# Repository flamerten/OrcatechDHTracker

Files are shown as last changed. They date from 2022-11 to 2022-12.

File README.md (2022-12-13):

# Orcatech DH Tracker

This is the GitHub repository for the Dining Hall Capacity Tracking project.

The process has been documented in this report: [Orcatech DH Project Report](./Orcatech_DHProject_Report.md)

The remaining contents of the repository are arranged as follows:

| Directory | Contents |
| --- | --- |
| [Electrical](./Electrical/) | Schematic and PCB design for the sensor nodes (designed using EasyEDA) |
| [Mechanical](./Mechanical/) | Files for the 3D printed PCB enclosure (in STL and SLDPRT format) |
| [Firmware](./Firmware/) | ESP32 Arduino source code for the sensor nodes |
|[Software](./Software/) | Python scripts to host the Telegram Bot and handle MQTT communication between the ESP32s, along with instructions to set up the Raspberry Pi network services |

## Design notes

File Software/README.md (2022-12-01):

# Raspberry Pi Setup

## Network Architecture

As the ESP32s are unable to connect to WPA2-Enterprise networks, the Raspberry Pi hosts a WPA2-Personal network using the built-in WiFi interface card `wlan_internal` to creates an intranet hotspot. Using the hotspot, one can SSH into the Raspberry Pi. The Raspberry Pi also hosts an MQTT broker for the ESP32s communicate sensor information in real time. Since the ESP32s do not require internet access, no routing is done to `wlan_internal` and it is an isolated intranet. This also serves as a security feature to prevent external attacks on these IoT devices. For the Telegram Bot, the Raspberry Pi uses an external WiFi USB adapter (TP Link TL-WN722N) `wlan_external` to connect to the NUSNET WiFi and the internet. Note that NUSNET blocks SSH access within the network. Hence to access the Raspberry Pi, either connect to the intranet hotspot, or setup a virtual private network to route it out.

```mermaid
    graph LR

    dns((Internet))---nusnet(NUSNET<br>Wifi)

    subgraph wlan_external[wlan_external]
        nusnet---|SSH Blocked|rpi1
    end

    subgraph wlan_internal[wlan_internal]
        rpi2---esp1(ESP32<br>192.168.4.ww<br>Dynamic IP)
        rpi2---esp2(ESP32<br>192.168.4.xx<br>Dynamic IP)
        rpi2---esp3(ESP32<br>192.168.4.yy<br>Dynamic IP)
        rpi2---esp4(ESP32<br>192.168.4.zz<br>Dynamic IP)
    end

    ssh(("SSH"))-.-rpi3("NUSNET<br>Wifi")
    subgraph zt[vlan]
        rpi3
    end
    nusnet---|Virtual Routing|rpi3
    dns---nusnet
    dns----ssh

    rpi1["Raspberry Pi<br>(TP Link TL-WN722N)<br>172.31.xx.yy<br>Dynamic IP"]
    rpi2["Raspberry Pi<br>(Built-In WiFi)<br>192.168.4.1<br>Static IP"]
    rpi3["Raspberry Pi<br>(VPN Instance)"]

    rpi1-.-|"Internet Not Routed"|rpi2
    rpi3-.-rpi2

    linkStyle 7 stroke-width:3px,fill:none,stroke:orange;
    linkStyle 8 stroke-width:3px,fill:none,stroke:orange;
    linkStyle 9 stroke-width:3px,fill:none,stroke:orange;
```

## Setup instructions

### Prepare Hardware

Hardware

- Raspberry Pi 3 Model B+
- TP Link TL-WN722N 150 Mbps High Gain Wireless USB Adapter

Install official Raspberry Pi OS.

### Change hostname

Go to `sudo raspi-config` and change hostname to `orcatechdiningpi`

After rebooting, we can SSH using the hostname from now on
    
    sshpass -p raspberry ssh pi@orcatechdiningpi.local

### Setup Wifi Hardware

Connect TP Link TL-WN722N to USB port. Drivers are pre-installed on the official OS so it is plug-and-play.

Check that USB is detected

    $ lsusb
    Bus 001 Device 004: ID 2357:010c TP-Link TL-WN722N v2/v3 [Realtek RTL8188EUS]

Check which interface belongs to which hardware. We can also get the MAC address of each device.

    $ ethtool -i wlan0
        driver: r8188eu
        version: 5.10.63-v7+

    $ ethtool -i wlan1
        driver: brcmfmac
        version: 7.45.229

    $ ip link
        3: wlan0: <BROADCAST,MULTICAST> mtu 1500 qdisc noop state DOWN mode DEFAULT group default qlen 1000
            link/ether 14:eb:b6:95:2f:2c brd ff:ff:ff:ff:ff:ff
        4: wlan1: <NO-CARRIER,BROADCAST,MULTICAST,UP> mtu 1500 qdisc pfifo_fast state DOWN mode DORMANT group default qlen 1000
            link/ether b8:27:eb:90:61:28 brd ff:ff:ff:ff:ff:ff

In this case, `wlan0` belongs to the USB adapter and `wlan1` is the built-in Wifi. Note that the numbers (`wlan0` and `wlan1`) may swap around sometimes, so let's fix a permanent name.

Let the USB adapter be called `wlan_external` and the built-in Wifi be `wlan_internal`

Make a rule in `rules.d` directory to set a name based on the adapter's MAC address.

    echo 'SUBSYSTEM=="net", ACTION=="add", DRIVERS=="?*", ATTR{address}=="14:eb:b6:95:2f:2c", ATTR{dev_id}=="0x0", ATTR{type}=="1", NAME="wlan_external"'  | sudo tee /etc/udev/rules.d/70-wlan_external.rules

    echo 'SUBSYSTEM=="net", ACTION=="add", DRIVERS=="?*", ATTR{address}=="b8:27:eb:90:61:28c", ATTR{dev_id}=="0x0", ATTR{type}=="1", NAME="wlan_internal"'  | sudo tee /etc/udev/rules.d/70-wlan_internal.rules

Reboot the Raspberry Pi. Verify that the name is persistent even after replugging the USB adapter.

    $ ip link
        3: wlan_internal: <BROADCAST,MULTICAST,UP,LOWER_UP> mtu 1500 qdisc pfifo_fast state UP mode DEFAULT group default qlen 1000
            link/ether b8:27:eb:90:61:28 brd ff:ff:ff:ff:ff:ff
        4: wlan_external: <NO-CARRIER,BROADCAST,MULTICAST,UP> mtu 1500 qdisc mq state DOWN mode DORMANT group default qlen 1000
            link/ether 14:eb:b6:95:2f:2c brd ff:ff:ff:ff:ff:ff
        
Test that the device can scan for surrounding Wifi SSIDs

    sudo iwlist wlan_external scan

### Setup Intranet Hotspot

Adapted from these guides:

- https://www.raspberrypi.com/documentation/computers/configuration.html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
- https://learn.adafruit.com/setting-up-a-raspberry-pi-as-a-wifi-access-point/install-software

#### Install AP and Management Software

    sudo apt install hostapd
    sudo systemctl unmask hostapd
    sudo systemctl enable hostapd
    sudo apt install dnsmasq
    sudo DEBIAN_FRONTEND=noninteractive apt install -y netfilter-persistent iptables-persistent

#### Set up the Network Router

As the dining network will be an intranet, we just need to set a static IP network but do not need to do any routing.

    sudo nano /etc/dhcpcd.conf

Go to the end of the file and add the following:

    interface wlan_internal
        static ip_address=192.168.4.1/24
        nohook wpa_supplicant

#### Configure the DHCP and DNS services for the wireless network

We set up DHCP in the dining network so the ESP32s will get their own IP addresses.

Rename the default configuration file and edit a new one:

    sudo mv /etc/dnsmasq.conf /etc/dnsmasq.conf.orig
    sudo nano /etc/dnsmasq.conf

Add the following to the file and save it. 

    interface=wlan_internal # Listening interface
    dhcp-range=192.168.4.2,192.168.4.254,255.255.255.0,24h
                    # Pool of IP addresses served via DHCP
    domain=wlan     # Local wireless DNS domain
    address=/orcatechdiningpi.wlan/192.168.4.1
                    # Alias for this router

The above configuration means the Raspberry Pi will deliver Class C IP addresses between `192.168.4.2` and `192.168.4.254`, with a lease time of 24 hours, to wireless DHCP clients.

The Raspberry Pi acts as a router at the address `192.168.4.1` and hostname `orcatechdiningpi.wlan`.

#### Configure the AP Software

Create the hostapd configuration file, located at `/etc/hostapd/hostapd.conf`, to add the various parameters for your new wireless network.

    sudo nano /etc/hostapd/hostapd.conf

Set the configuration to the following. Note the SSID (`orcatech_dining_bot`) and passphrase (`ORCATECH_DINING_BOT_PASSWORD`) of our dining network.

    country_code=SG
    interface=wlan_external
    ssid=orcatech_dining_bot
    hw_mode=g
    channel=7
    macaddr_acl=0
    auth_algs=1
    ignore_broadcast_ssid=0
    wpa=2
    wpa_passphrase=ORCATECH_DINING_BOT_PASSWORD
    wpa_key_mgmt=WPA-PSK
    wpa_pairwise=TKIP
    rsn_pairwise=CCMP
    max_num_sta=100

Check both services are active

    sudo service dnsmasq status
    sudo service hostapd status

### Setup Internet Wifi

The TP Link TL-WN722N does not support the default wpa_supplicant driver (`nl80211`) in access point mode. [Manually change to the `wext` driver](https://unix.stackexchange.com/questions/558081/manually-set-wpa-supplicant-driver) instead.

Add this to the end of `/etc/dhcpcd.conf`. Note that the DNS servers must be set as well, because `dhcpcd` overrides the system `resolv.conf`.
In addition, IPv4 Link-Local address is disabled to speed up DHCP IP address allocation.

    interface wlan_external
        env ifwireless=1
        env wpa_supplicant_driver=wext
        static domain_name_servers=8.8.8.8 4.2.2.1
        nohook resolv.conf
        noipv4ll

    interface eth0
        static domain_name_servers=8.8.8.8 4.2.2.1

Also manually set up domain name server if it gets overridden by dhcpd. `sudo nano /etc/resolv.conf`:

    nameserver 8.8.8.8

#### For WPA2 connections

Instead of putting your plaintext password, generate a passphrase using this command

    wpa_passphrase YOUR_SSID YOUR_PASSWORDS

Create a new file to specify the wifi connection for the interface `wlan_external`. ([Reference](https://superuser.com/questions/469039/wpa-supplicant-for-dual-wlan))

    sudo nano /etc/wpa_supplicant/wpa_supplicant-wlan_external.conf

Copy it to wpa_supplicant.conf

    network={
            ssid="my_wifi_network"
            #psk="helloworld"
            psk=0b6aef02bb483a725f72c64856d3d2677ac1ea6546a602318cad8bbb06ee33f1
    }

#### For WPA2-Enterprise connections

Instead of putting your plaintext password, generate a hash using this command

    echo -n "plaintext_password_here" | iconv -t utf16le | openssl md4 -provider legacy

Use this template instead. Ensure your password is prefixed with `hash:`.

    network={
        ssid="NUS_STU"
        scan_ssid=1
        proto=RSN
        key_mgmt=WPA-EAP
        group=CCMP
        pairwise=CCMP
        auth_alg=OPEN
        eap=PEAP
        phase1="peaplabel=0"
        phase2="auth=MSCHAPV2"
        identity="e1234567"
        password=hash:0123456789abcdef0123456789abcdef
        priority=1
    }

After changing the wpa_supplicant, reload the wifi connection and check if it connects

    wpa_cli -i wlan_external reconfigure
    wpa_cli -i wlan_external status

### Install MQTT broker

Install `mosquitto` and start it.

    sudo apt install mosquitto
    sudo apt install mosquitto-clients
    sudo systemctl enable mosquitto
    sudo systemctl start mosquitto

Allow external connections. Add this to the end of `/etc/mosquitto/mosquitto.conf`.

    listener 1883
    allow_anonymous true

Test that MQTT works between different devices. On another device, run the following:

- Subscribe to the topic: `mosquitto_sub -v -t 'dh_topic/#' -h orcatechdiningpi.local`
- Publish a message: `mosquitto_pub -t 'dh_topic/test/123' -m 'helloWorld' -h orcatechdiningpi.local`

Alternatively, install MQTTX on your PC to test using a GUI

    sudo snap install mqttx

### Start scripts on boot

Install tmuxinator to manage the scripts

    sudo apt install tmux

Add a main launch script in the home directory

    nano /home/pi/BOOT_SCRIPT.sh

Paste this into the BOOT_SCRIPT.sh

```bash
# Debug Left Pane
tmux new-session -d -s Orcatech -n 'Debug'
tmux set -g mouse on
tmux send-keys 'echo $(date)' Enter
tmux send-keys 'cd ~/DH-CrowdTracker' Enter

# Debug Right Pane
tmux split-window -h
tmux send-keys 'cd ~/DH-CrowdTracker' Enter

# MQTT Left Top Pane
tmux new-window -n 'MQTT'
tmux send-keys 'sudo less +F /var/log/mosquitto/mosquitto.log' Enter

# MQTT Right Pane
tmux split-window -h
tmux send-keys 'mosquitto_sub -v -t "dh_topic/#" -F "%I %t %p"' Enter

# MQTT Left Bottom Pane
tmux selectp -t 0
tmux split-window -v
tmux send-keys 'cd ~/DH-CrowdTracker' Enter
tmux send-keys 'bash nmap_script.sh' Enter

# Wifi Left Top Pane
tmux new-window -n 'Wifi'
tmux send-keys 'wpa_cli -i wlan_external status' Enter

# Wifi Right Pane
tmux split-window -h
tmux send-keys 'less +F /var/log/syslog' Enter

# Wifi Left Bottom Pane
tmux selectp -t 0
tmux split-window -v
tmux send-keys 'iw dev wlan_internal station dump' Enter

# Telegram_Bot Left Pane
tmux new-window -n 'Telegram_Bot'
tmux send-keys -t Orcatech:Telegram_Bot 'cd /home/pi/DH-CrowdTracker && while true; do python3 esp32_control_main.py; done' Enter

# Telegram_Bot Right Pane
tmux split-window -h
tmux send-keys -t Orcatech:Telegram_Bot 'cd /home/pi/DH-CrowdTracker && while true; do python3 telegram_main.py; date; done' Enter
```

Now when you SSH in, you can view the session using this

    tmux attach -t Orcatech
    tmux list-sessions

Edit the rc.local script launched on boot

    sudo nano /etc/rc.local

Add the line at the end just before `exit 0`.

    sudo su pi -c "bash /home/pi/BOOT_SCRIPT.sh &"

### Install additional services (optional)

Install zerotier so that we can SSH in remotely. [(Full instructions here)](https://pimylifeup.com/raspberry-pi-zerotier/).

    curl https://raw.githubusercontent.com/zerotier/ZeroTierOne/master/doc/contact%40zerotier.com.gpg | gpg --dearmor | sudo tee /usr/share/keyrings/zerotierone-archive-keyring.gpg >/dev/null
    RELEASE=$(lsb_release -cs)
    echo "deb [signed-by=/usr/share/keyrings/zerotierone-archive-keyring.gpg] http://download.zerotier.com/debian/$RELEASE $RELEASE main" | sudo tee /etc/apt/sources.list.d/zerotier.list
    sudo apt update
    sudo apt install -y zerotier-one

Then join your zerotier network.

    sudo zerotier-cli join [NETWORKID]
    sudo zerotier-cli listnetworks

Install privoxy to have a HTTP proxy for access to `wlan_internal` network over a web browser. [(Full instructions here)](https://www.howtogeek.com/683971/how-to-use-a-raspberry-pi-as-a-proxy-server-with-privoxy/).

    sudo apt install -y privoxy
    sudo nano /etc/privoxy/config    # Replace the line with the following: `listen-address :8118`
    sudo systemctl restart privoxy
    sudo systemctl status privoxy

Now connect by setting your PC web browser to point to the following HTTP proxy

    orcatechdiningpi.local:8118

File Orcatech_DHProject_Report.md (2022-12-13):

# Orcatech DH Project Report

National University Of Singapore, Residential College 4

Done by:
- Yow Keng Yee Samuel (Class of 2024)
- Manzel Joseph Seet (Class of 2023)

Supervised by:
- Prof Naviyn Prabhu Balakrishnan

## Rationale

This project was started in AY2021/2022 Sem 2 when the Dinning Hall capacity was reduced due to Covid-19 Safe Management Measures. As the Dinning Hall could get quite crowded with long queues, we proposed the idea of utlising sensors at the doors of the dinning hall to track people coming into and out of the Dinning Hall so as to calculate the current number of people at any point in time. This would allows residents to make informed decsions on when to come down to get their food.

## List of Items Purchased
- VLX53L0X Laser Ranging Time Of Flight Sensor 
- VL53l1X Laser Ranging Time Of Flight Sensor
- Generic Dual USB Charger 
- Generic MircoUSB Cable
- ESP32 Dev Kit
- Raspberry Pi 3B
- High gain Wireless USB Adaptor TP Link [shoppee](https://shopee.sg/TP-Link-TL-WN722N-150-Mbps-High-Gain-Wireless-USB-Adapter-White-TPLink-i.101600.2161518348)
- [JLCPCB](https://jlcpcb.com/) - PCB Printing Service

## Relevant Links
- VL53L0X Laser Ranging Time Of Flight Sensor
    - Github [Library](https://github.com/adafruit/Adafruit_VL53L0X) 
    - Adafruit [Tutorial](https://learn.adafruit.com/adafruit-vl53l0x-micro-lidar-distance-sensor-breakout)
- ESP32
    - Over The Air Update (OTA) [Tutorial](https://randomnerdtutorials.com/esp32-over-the-air-ota-programming/)

## Fabrication and Installation

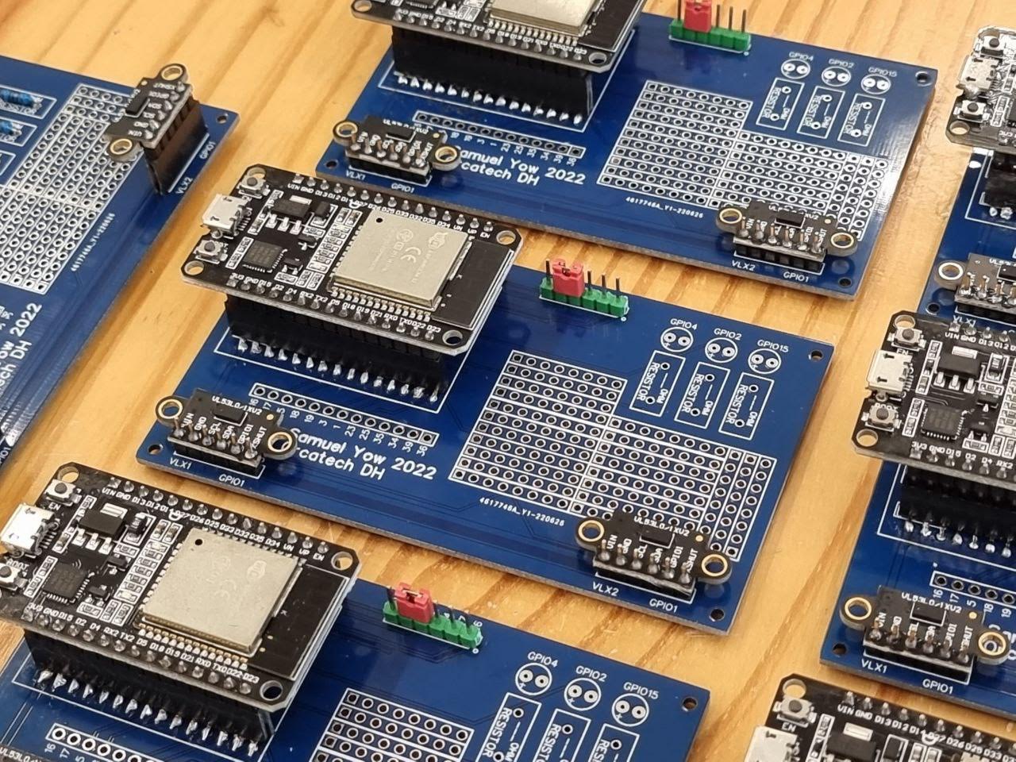
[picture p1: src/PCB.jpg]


[EasyEDA](https://easyeda.com/) was used to design the PCB, which contained the ESP32s and the VLX distance sensors. This was sent over to JLCPCB to be printed. However, the ESP32 did not fit the PCB exactly. Hence, the base of female pin headers was bent and sodlered on top of the through holes.

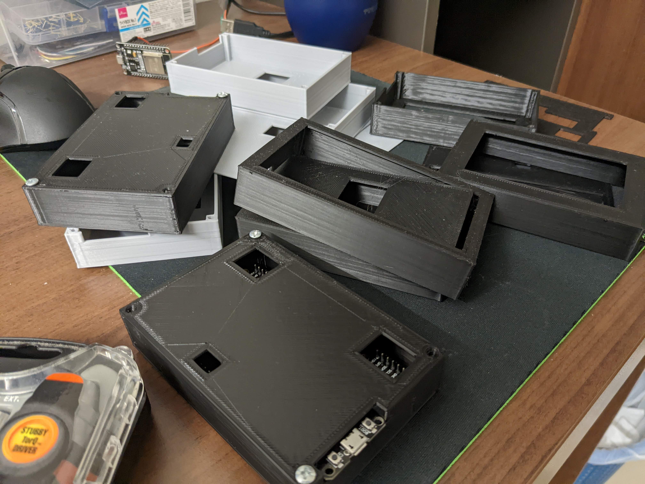
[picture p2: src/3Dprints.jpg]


For the casing, PLA filament with a 3D printer was used to prototype various methods of encasing the PCB. We initially tried using friction fitting but it was hard to get an accurate fit and we realised it might encourage tampering as any resident could remove a friction fit. Hence, our final iteration used screws to secure the cover.

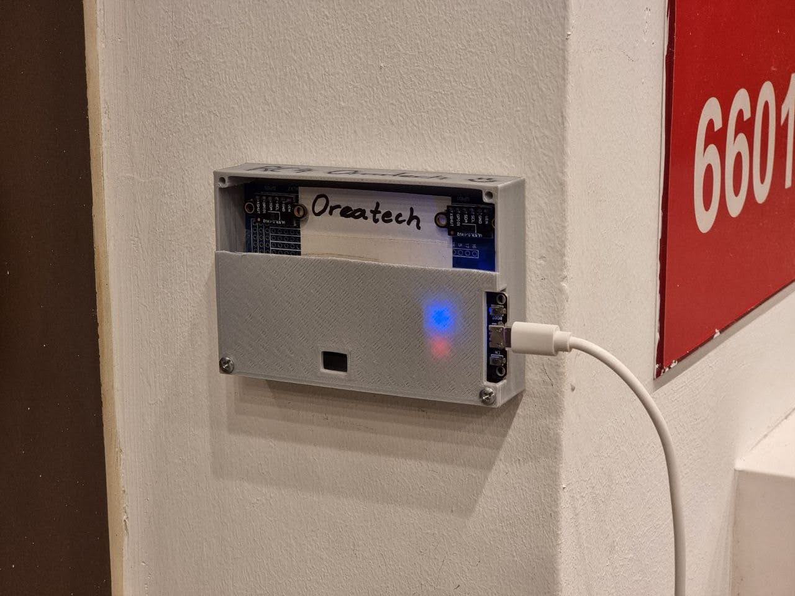
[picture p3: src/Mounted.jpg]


The casing was mounted on to the pillars of the Dinning Hall using mounting tape. Transparent tape was used to tape down the wires to the walls. From some initial testing, we made some observations, which can be improved upon during the next iteration
- Mounting Tape is quite permanant and when taken out, paint is removed as well.
- The cover was cut as it seemed to block the VLX sensor's line of vision.
- One of the ESP32s were damanaged when the USB port broke off. We believe someone accidentally presed against it leading to the USB port being removed from the ESP32 board. Hence, that board needed to be swapped out. As such, future iterations need to consider such a scenario.
- After a month of installation, the wires and tape accumulated dust. A more permanant installation should be considered

## Data

Data was collected for around 2 months, and plotted using the `graph_plotter.py` file. The raw data is also attached in the src folder [here](src/DHCapacityRecords.csv).

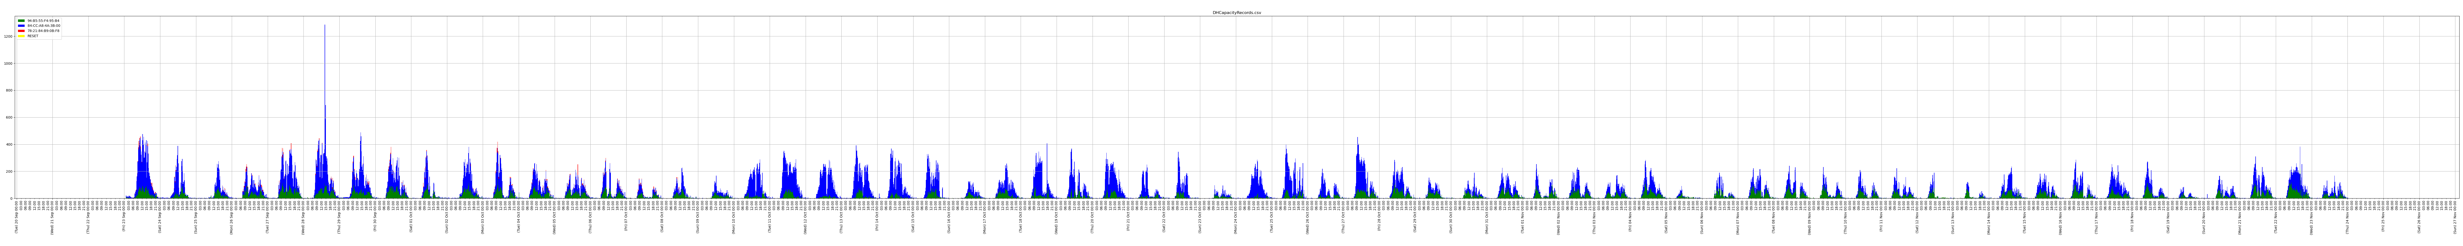
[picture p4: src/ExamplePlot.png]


From testing at night, we had a success rate of around 70% with very few false triggers. This was done by shifting the sensors away from the door. Its shiny handle was suspected to cause the false triggering. From the data collected over a few days, the two sensors at the main doors were found to be quite inaccurate. From the data, the number of people going in appeared to peak at around 12pm. The sensor at the side door seemed to be working fine. We suspected that the anamolies were due to UV rays from the sun which peaked that that timing. As the side door seemed to work fine, the inaccuracies of the sensor could also be due to the wide width of the main doors. 

We purchased the VLX53L1X to test this due to its higher range of 30mm to 4000mm. However, we found the sensor to be unreliable, with 3 out of 4 sensors being extremely noisy. The blue line in the graph below represents the good esnsor while the red line is the noisy sensor.

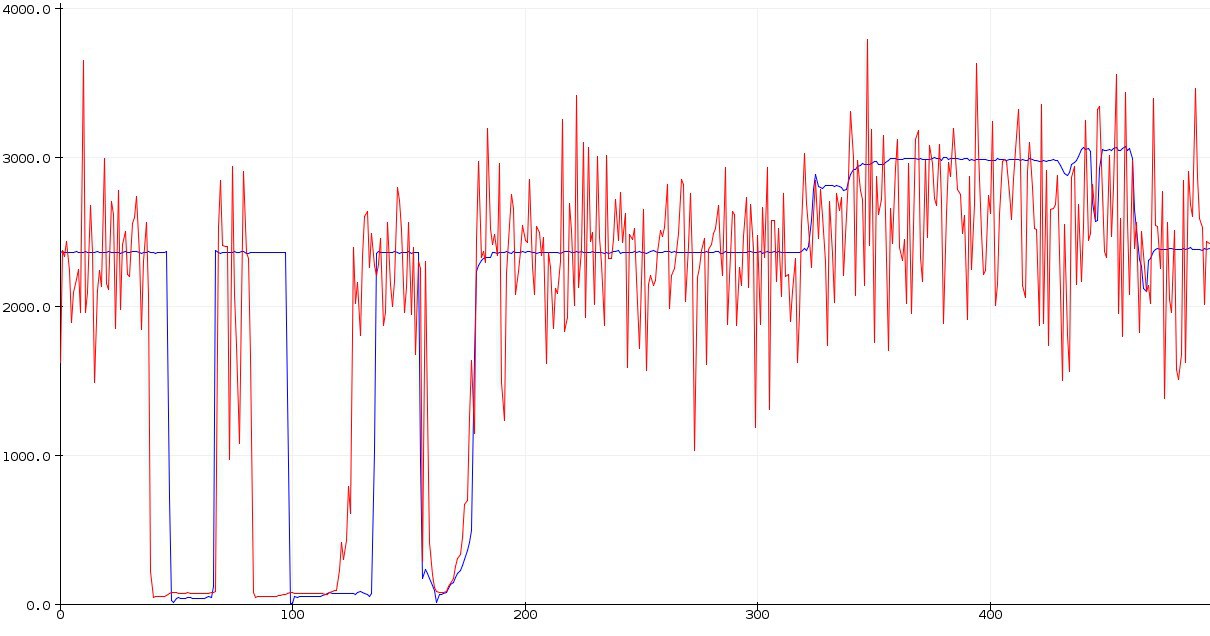
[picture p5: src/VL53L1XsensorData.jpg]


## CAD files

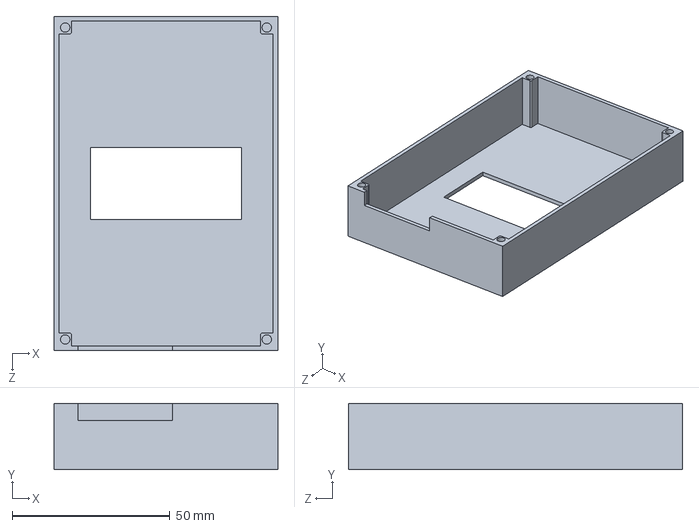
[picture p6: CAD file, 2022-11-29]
Mechanical/BaseScrew.SLDPRT
71.0 x 21.0 x 106.0 mm

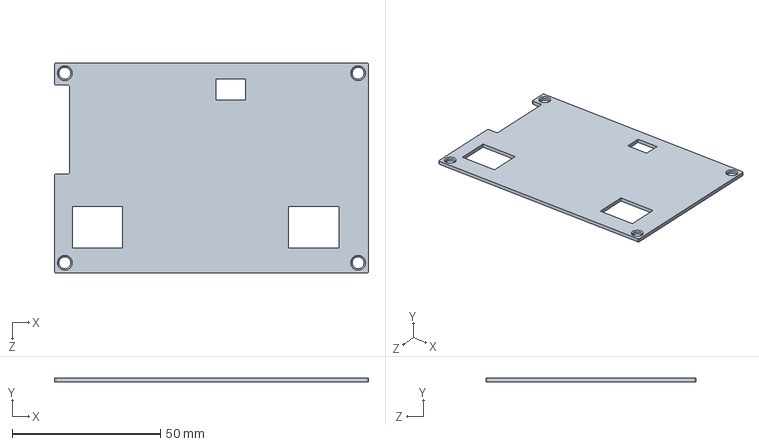
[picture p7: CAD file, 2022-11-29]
Mechanical/CoverScrew.SLDPRT
106.0 x 1.50 x 71.0 mm

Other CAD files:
Mechanical/BaseScrew.STL
Mechanical/CoverScrew.STL

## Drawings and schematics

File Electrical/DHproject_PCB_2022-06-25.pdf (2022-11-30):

## Resistor

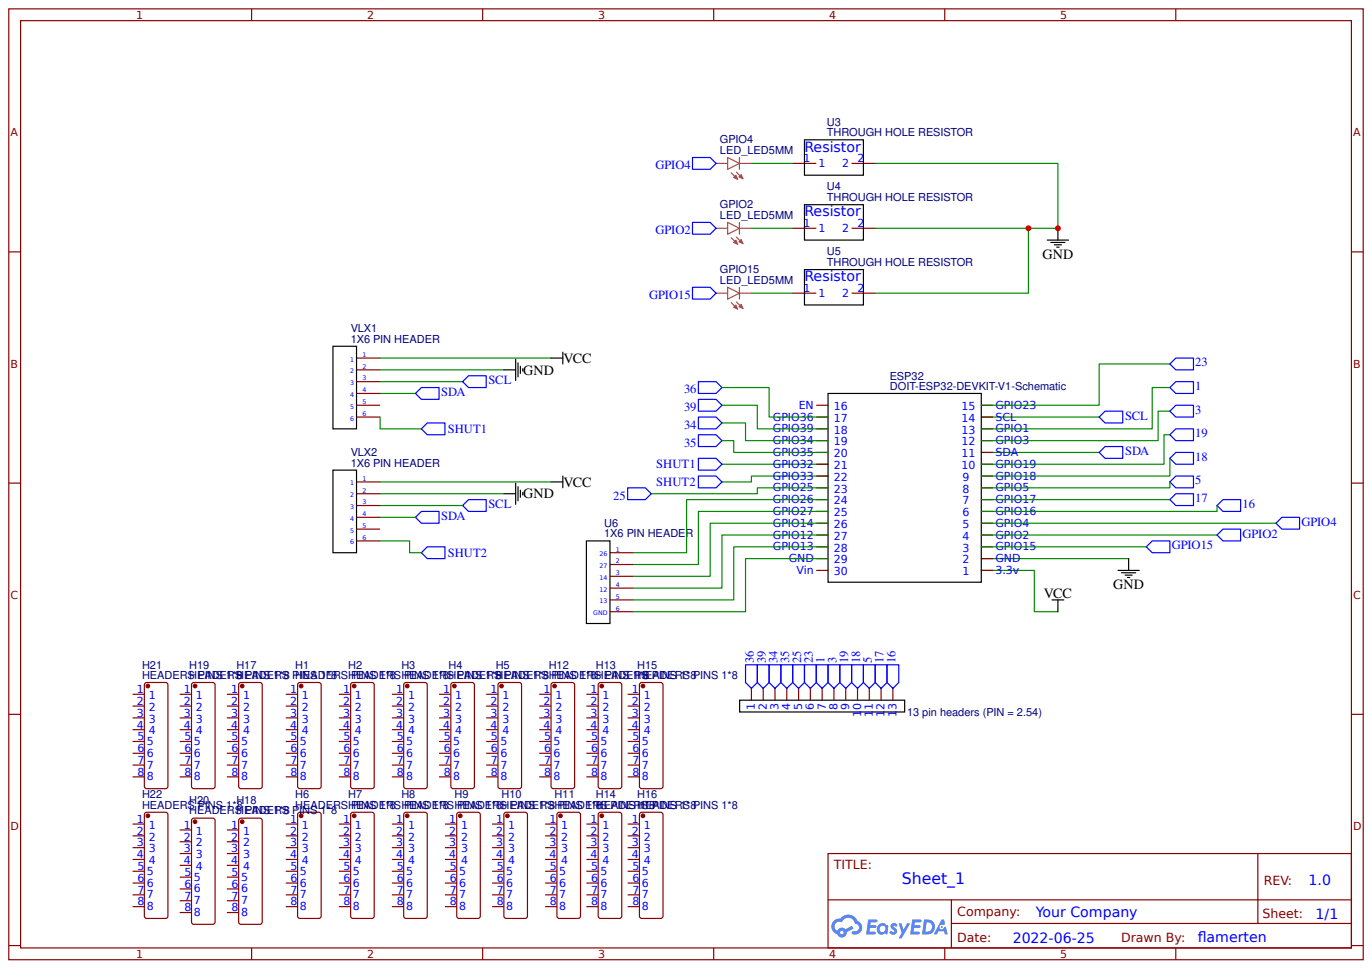
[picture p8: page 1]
TITLE:; Sheet_1; REV: 1.0; Date:; Sheet: 1/1; VCC; GND; SCL; SDA; SHUT2; SHUT1; GND VCC; GPIO36; GPIO39; GPIO34; GPIO35; GPIO32; GPIO33; GPIO25; GPIO26; GPIO27; GPIO14; GPIO12; GPIO13; Vin; GPIO23; GPIO1; GPIO3; GPIO19; GPIO18; GPIO5; GPIO17; GPIO16; GPIO4; GPIO2; GPIO15; 1X6 PIN HEADER; VLX1; VLX2; LED_LED5MM; THROUGH HOLE RESISTOR; 2 2 LED_LED5MM Resistor GPIO2; 2 2 LED_LED5MM Resistor GPIO15; GND 6; HEADERS PINS 1*8

THROUGH HOLE RESISTOR

ESP32
DOIT-ESP32-DEVKIT-V1-Schematic

13 pin headers (PIN = 2.54) ¹

Company: Your Company

Drawn By: flamerten

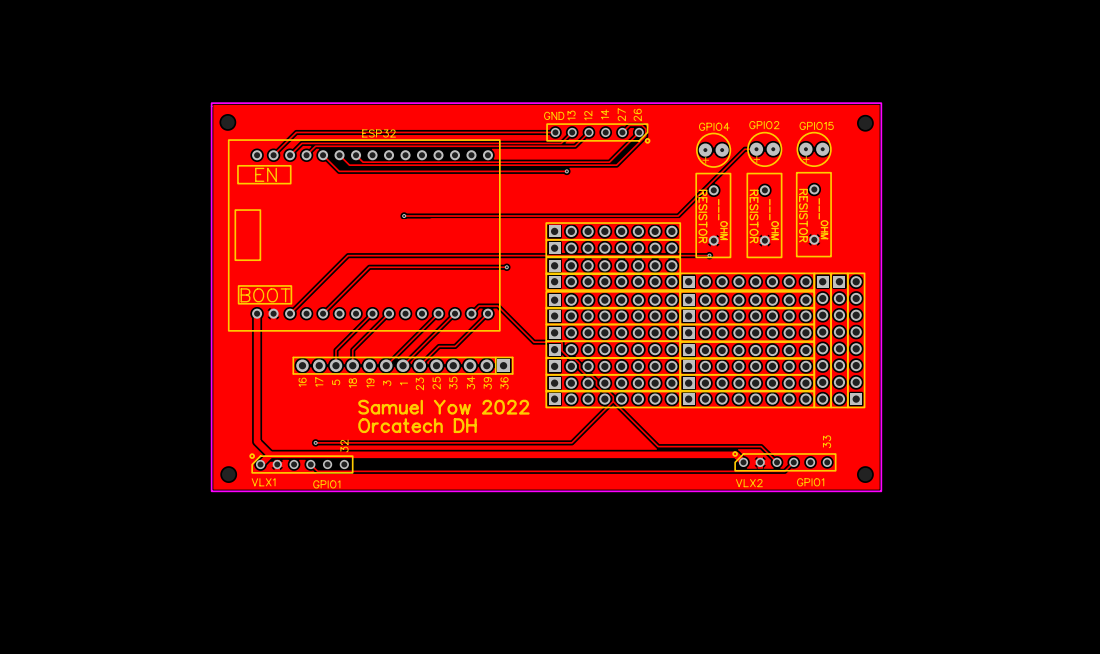
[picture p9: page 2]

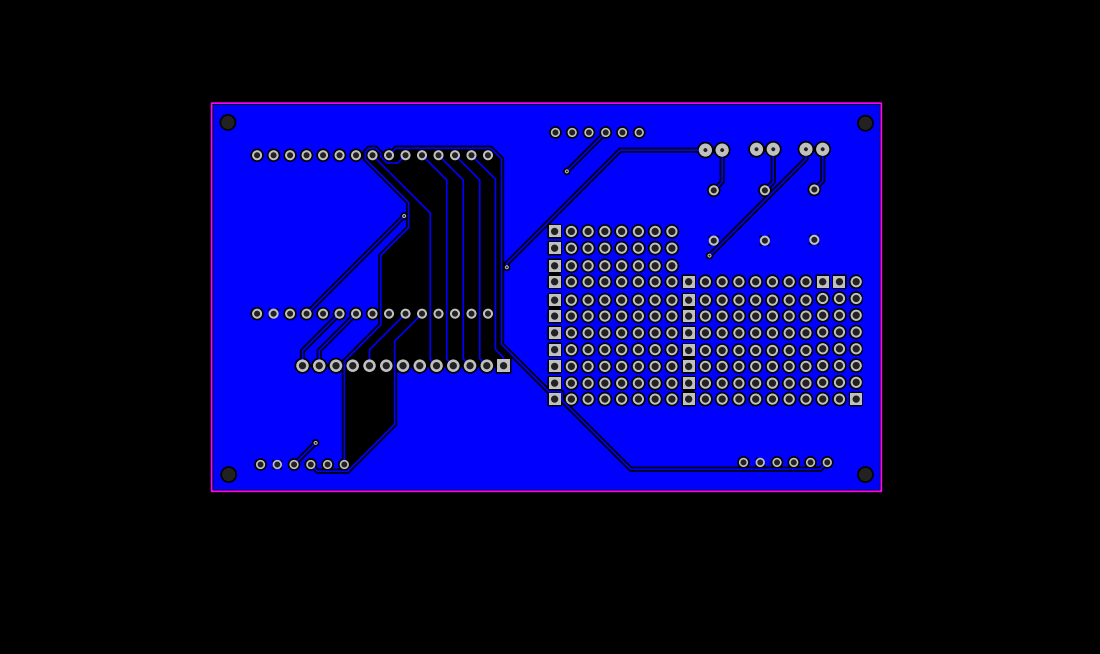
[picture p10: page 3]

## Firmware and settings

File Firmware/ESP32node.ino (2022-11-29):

// Wemos® D1 R32
// Board: ESP32 Dev Module

#include "EspMQTTClient.h"
#include "Adafruit_VL53L0X.h"
#include <Wire.h>
#include <WiFi.h>
#include <AsyncTCP.h>
#include <ESPAsyncWebServer.h>
#include <AsyncElegantOTA.h>

AsyncWebServer server(80); //For OTA updates


//VLX
#define LOX1_ADDRESS 0x30
#define LOX2_ADDRESS 0x31
#define SHT_LOX1 33
#define SHT_LOX2 32

Adafruit_VL53L0X lox1 = Adafruit_VL53L0X();
Adafruit_VL53L0X lox2 = Adafruit_VL53L0X();

int RANGE_DIFF1;
int RANGE_DIFF2;

#define LEDPCB    15
#define LEDBOARD  2

//direction PINS
//connect these 2 pins together to reverse the direction
//if connected, going in(Addition) means that VLX1 is triggered first (shut pin  32)
//if disconnected, going in means that VLX2 is triggered first (shut pin 33)
#define GPIO_INPUT    13
#define GPIO_OUTPUT   12

#define DELAYVAL   500 //prevent false triggering 15cm
const int ping_time = 10 * 60 * 1000; //10mins 
int ping_now = millis();


//debugging parameters, allows us to remove wifi and the serial printouts during production
const bool debugging = true;  
const bool wifi_off = false;
int counter = 0; //debugging

// Dining Wifi
const char * WifiSSID = "orcatech_dining_bot";
const char * WifiPassword = "ORCATECH_DINING_BOT_PASSWORD";
EspMQTTClient * WifiClient;
String WifiMAC;

// MQTT parameters
const char * MQTTServerIP = "192.168.4.1"; // RPi configured to this static IP
bool MQTTConnected = false;

uint16_t lo_cal[2] = {0,0};
 
//direction
bool lox1_in;

bool in_act = false; 
bool out_act = false;
int start_time;
bool wifi_connected = true;
int disconnect_time;

void setID() {
  /*
    Reset all sensors by setting all of their XSHUT pins low for delay(10), then set all XSHUT high to bring out of reset
    Keep sensor #1 awake by keeping XSHUT pin high
    Put all other sensors into shutdown by pulling XSHUT pins low
    Initialize sensor #1 with lox.begin(new_i2c_address) Pick any number but 0x29 and it must be under 0x7F. Going with 0x30 to 0x3F is probably OK.
    Keep sensor #1 awake, and now bring sensor #2 out of reset by setting its XSHUT pin high.
    Initialize sensor #2 with lox.begin(new_i2c_address) Pick any number but 0x29 and whatever you set the first sensor to
 */

  // all reset
  digitalWrite(SHT_LOX1, LOW);    
  digitalWrite(SHT_LOX2, LOW);
  delay(10);
  // all unreset
  digitalWrite(SHT_LOX1, HIGH);
  digitalWrite(SHT_LOX2, HIGH);
  delay(10);

  // activating LOX1 and resetting LOX2
  digitalWrite(SHT_LOX1, HIGH);
  digitalWrite(SHT_LOX2, LOW);

  // initing LOX1
  if(!lox1.begin(LOX1_ADDRESS)) {
    if(debugging) Serial.println(F("Failed to boot first VL53L0X"));
    while(1);
  }
  delay(10);

  // activating LOX2
  digitalWrite(SHT_LOX2, HIGH);
  delay(10);

  //initing LOX2
  if(!lox2.begin(LOX2_ADDRESS)) {
    if(debugging) Serial.println(F("Failed to boot second VL53L0X"));
    while(1);
  }
}

void VLXsetup(){
  //Initalise Pins, Set i2c IDs, and configure lox
  pinMode(SHT_LOX1, OUTPUT);
  pinMode(SHT_LOX2, OUTPUT);

  if(debugging) Serial.println(F("Shutdown pins inited..."));

  digitalWrite(SHT_LOX1, LOW);
  digitalWrite(SHT_LOX2, LOW);

  if(debugging) Serial.println(F("Both in reset mode...(pins are low)"));
  if(debugging) Serial.println(F("Starting..."));

  setID(); //Assign I2C address to the VLXes


  //set to long range, we found high speed was unable to detect movement for certain doors
  lox1.configSensor(Adafruit_VL53L0X::VL53L0X_SENSE_LONG_RANGE);
  lox2.configSensor(Adafruit_VL53L0X::VL53L0X_SENSE_LONG_RANGE);

  lox1.setDeviceMode(VL53L0X_DEVICEMODE_CONTINUOUS_RANGING);
  lox2.setDeviceMode(VL53L0X_DEVICEMODE_CONTINUOUS_RANGING);
  
  lox1.startRangeContinuous();
  lox2.startRangeContinuous();
}

void Blink(int LED){
  digitalWrite(LED,HIGH);
  delay(100);
  digitalWrite(LED,LOW);
  delay(100);
}

bool DirectionInOut(){
  //use this to decide which direction.
  //connect GPIO 13 to 26 to set direction as positive
  //not connected > default hit lox1 going in
  //connected > hit lox1 means going out

  pinMode(GPIO_INPUT,INPUT);
  pinMode(GPIO_OUTPUT,OUTPUT);

  delay(100);

  digitalWrite(GPIO_OUTPUT,HIGH);

  delay(100);
  if(digitalRead(GPIO_INPUT) == HIGH){
    digitalWrite(GPIO_OUTPUT,LOW);
    return false;
  }

  digitalWrite(GPIO_OUTPUT,LOW);
  return true;

}

void LoCalibrate(){
  //Calibration - if the wall is near, then a lower distance is needed to trigger the VLX

  uint16_t range1, range2, t1,t2;
  //Set t1, t2 as the maximum
   
  t1 = 10000;
  t2 = 10000;

  for(int i = 0;i<50; i++){
    while(!lox1.isRangeComplete() && !lox2.isRangeComplete()){}
    range1 = lox1.readRangeResult();
    range2 = lox2.readRangeResult();

    if(range1 > 10000) range1 = 2000;
    if(range2 > 10000) range2 = 2000;
    
    //We use minimum rather than the average
    t1 = min(t1,range1);
    t2 = min(t1,range2);
    
    delay(10);
  }

  lo_cal[0] = t1;
  lo_cal[1] = t2;

  
  digitalWrite(LEDBOARD,LOW);

  RANGE_DIFF1 = 0.25 * t1;
  RANGE_DIFF2 = 0.25 * t2;


  if(debugging) Serial.println("Calibration");
  if(debugging) Serial.println(lo_cal[0]);
  if(debugging) Serial.println(lo_cal[1]);


}

void setupOTA(){
  if(wifi_off) return;
  server.on("/", HTTP_GET, [](AsyncWebServerRequest *request) {
    request->send(200, "text/plain", ("Hi! I am ESP32." + WiFi.macAddress() ));
  });

  AsyncElegantOTA.begin(&server);    // Start ElegantOTA
  server.begin();
  Serial.println("HTTP server started");  
}

void setup() {
  Serial.begin(115200);
  Wire.begin(21,22,1000000LU);

  pinMode(LEDPCB,   OUTPUT);
  pinMode(LEDBOARD, OUTPUT);

  digitalWrite(LEDBOARD,LOW); 

  VLXsetup();
  LoCalibrate();  //Calibrate when no one is at the sensors
  lox1_in = DirectionInOut(); //Set the direction based on the jumper wires

  if(!lox1_in){
    digitalWrite(LEDPCB,HIGH); // set led to be on when the non-default it set
    if(debugging) Serial.println("LOX1 > LOX2 = IN");
  }
  else{
    digitalWrite(LEDPCB,LOW);
    if(debugging) Serial.println("LOX2 > LOX1 = IN");
  }
 
  DiningWifi_Setup();
  setupOTA(); //Comes after due to wifi
  delay(1000);

  digitalWrite(LEDBOARD,HIGH); //Turn on LED once set up has finished
}


void loop() {
  DiningWifi_Loop(); //MQTT

  uint16_t range1 = lox1.readRangeResult();
  uint16_t range2 = lox2.readRangeResult();

  uint16_t range1_thresh = lo_cal[0]-RANGE_DIFF1; //to activate
  uint16_t range2_thresh = lo_cal[1]-RANGE_DIFF2;

  if(range1 == 0 || range1 >2000){
    range1 = 2000; // constrain to max length
  }
  
  if(range2 == 0|| range2>2000){
    range2 = 2000; // constrain to max length
  }


  if( !in_act && !out_act){
    if( (range1 < range1_thresh) && (range2 < range2_thresh) ){
      delay(1); //Both are actiavted, just continue
     }
    else if(range1<range1_thresh){
      in_act = true;
      start_time = millis();
    }
    else if(range2<range2_thresh){
      out_act = true;
      start_time = millis();
    }
  }
    

  if(millis() - start_time > 500 ){
    in_act = false;
    out_act = false;
  }

  else if(in_act){
    if(range2 < range2_thresh){
      in_act = false;
      if(debugging){
        Serial.print(range1);
        Serial.print(" ");
        Serial.println(range2);
      }

      if(lox1_in){
        counter++;
        DiningWifi_HandleIncrement();
//        if(debugging) Serial.println(counter);
//        if(debugging) Serial.println("Increase");
      }
      else{
        counter--;
        DiningWifi_HandleDecrement();
//        if(debugging) Serial.println(counter);
//        if(debugging) Serial.println("Decrease");
      }

      delay(DELAYVAL);
    }
  

  }

  else if(out_act){
    if(range1 < range1_thresh){
      out_act = false;
      if(debugging){
        Serial.print(range1);
        Serial.print(" ");
        Serial.println(range2);
      }
      
      if(lox1_in){
        counter--;
        DiningWifi_HandleDecrement();
//        if(debugging) Serial.println(counter);
//        if(debugging) Serial.println("Decrease");
      }
      else{
        counter++;
        DiningWifi_HandleIncrement();
//        if(debugging) Serial.println(counter);
//        if(debugging) Serial.println("Increase");
      }

      delay(DELAYVAL);
    }
      
  }

  if(!wifi_off && WiFi.status() != WL_CONNECTED){
    //If wifi is not connected, change flag, start time, attempt reconnection
    if(wifi_connected == true){
      disconnect_time = millis();
      wifi_connected = false;
    }

    WiFi.disconnect();
    WiFi.reconnect();
    
  }
  else if(!wifi_off && wifi_connected == false && WiFi.status() == WL_CONNECTED){
    //If there is connection, AND it was previously not connected, reset flag, send time taken to connect back
    wifi_connected = true;
    Wifi_ReconnectTime(millis() - disconnect_time);

  }
  
  //PING
  if(millis() - ping_now >= ping_time){
    Wifi_PingConnection();
    ping_now = millis(); //RESET time
  }
  
  
  //Debugging purposes
  if(debugging) Serial.print(range1);
  if(debugging) Serial.print(" ");
  if(debugging) Serial.print(range2);
  if(debugging) Serial.print(" ");
  if(debugging) Serial.println(counter);
  


}

void DiningWifi_Setup() {
  // Get device MAC address
  if(wifi_off) return;
  if(debugging) Serial.print("ESP Board MAC Address:  ");
  WifiMAC = WiFi.macAddress();
  if(debugging) Serial.println(WifiMAC);

  // Start Wifi with MQTT
  WifiClient  = new EspMQTTClient(
    WifiSSID, // WifiSSID
    WifiPassword, // WifiPassword
    MQTTServerIP,  // MQTT Broker server ip
    NULL,   // MQTTUsername, Can be omitted if not needed
    NULL,   // MQTTPassword, Can be omitted if not needed
    WifiMAC.c_str(),     // Client name that uniquely identify your device
    1883              // The MQTT port, default to 1883. this line can be omitted
  );

  // Optional functionalities of EspMQTTClient
  WifiClient->enableDebuggingMessages(); // Enable debugging messages sent to serial output
  //WifiClient.enableHTTPWebUpdater(); // Enable the web updater. User and password default to values of MQTTUsername and MQTTPassword. These can be overridded with enableHTTPWebUpdater("user", "password").
  //WifiClient.enableOTA(); // Enable OTA (Over The Air) updates. Password defaults to MQTTPassword. Port is the default OTA port. Can be overridden with enableOTA("password", port).
  //WifiClient->enableLastWillMessage("TestClient/lastwill", "I am going offline");  // You can activate the retain flag by setting the third parameter to true

  // Wait until connected to Wifi
  do {
    WifiClient->loop();
  } while(WiFi.status() != WL_CONNECTED);
  if(debugging) Serial.println("Connected to Wifi");
}

void DiningWifi_Loop() {
  if(wifi_off) return;
  // MQTT library handle
  WifiClient->loop();
}

void Wifi_PingConnection(){
  if(wifi_off || (WiFi.status() != WL_CONNECTED)) return;
  
  WifiClient->publish("dh_topic/connection/"+WifiMAC, "ESP32 connected -> ");
  
}

void Wifi_ReconnectTime(int time_taken){
  if(wifi_off || (WiFi.status() != WL_CONNECTED)) return;
  WifiClient->publish("dh_topic/reconnect/"+WifiMAC+"/"+String(time_taken), "ESP32 connected back");

}

void DiningWifi_HandleIncrement() {
  if(wifi_off) return;
  bool res = WifiClient->publish("dh_topic/increment/"+WifiMAC, "ESP32 connected");
  if(!res) digitalWrite(LEDBOARD,LOW);
  else digitalWrite(LEDBOARD,HIGH);
  return;
}

void DiningWifi_HandleDecrement() {
  if(wifi_off) return;
  bool res = WifiClient->publish("dh_topic/decrement/"+WifiMAC, "ESP32 connected");
  if(!res) digitalWrite(LEDBOARD,LOW);
  else digitalWrite(LEDBOARD,HIGH);
  return;
}

// This function is called once everything is connected (Wifi and MQTT)
// WARNING : YOU MUST IMPLEMENT IT IF YOU USE EspMQTTClient
void onConnectionEstablished() {
  // Publish a test message once we have connected
  if(wifi_off) return;
  WifiClient->publish("dh_topic/test/"+WifiMAC+"/"+WiFi.localIP().toString().c_str(), "ESP32 connected -> ");

  MQTTConnected = true;
}

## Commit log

2022-11-29 Added 3d, rpi and esp32 files, removed tokens
    [BaseScrew.SLDPRT, BaseScrew.STL, CoverScrew.SLDPRT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]
2022-11-29 Added Gerber Files, First Commit for Report
2022-11-30 Reorganised folders, added schematic and plotter script
    [BaseScrew.SLDPRT, BaseScrew.STL, CoverScrew.SLDPRT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]
